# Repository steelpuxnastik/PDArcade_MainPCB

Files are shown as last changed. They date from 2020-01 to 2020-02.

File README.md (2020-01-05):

# PCB mainboard (with changes) for a homemade arcade controller for Hatsune Miku Project DIVA Arcade Future Tone. Based on http://pol.dip.jp/diva/

First version (homemade)
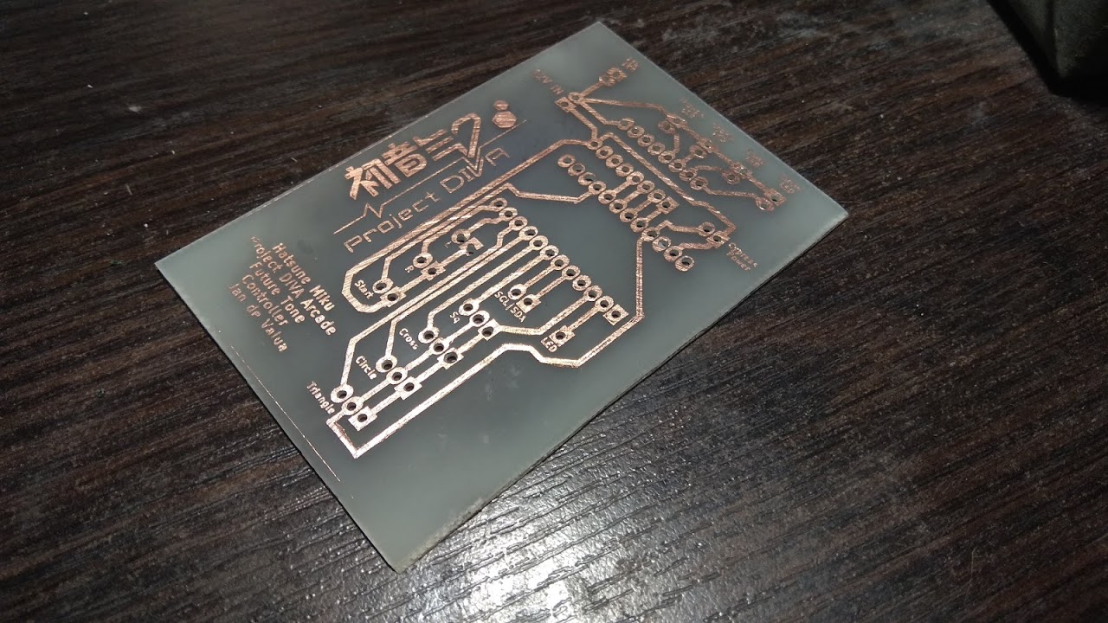
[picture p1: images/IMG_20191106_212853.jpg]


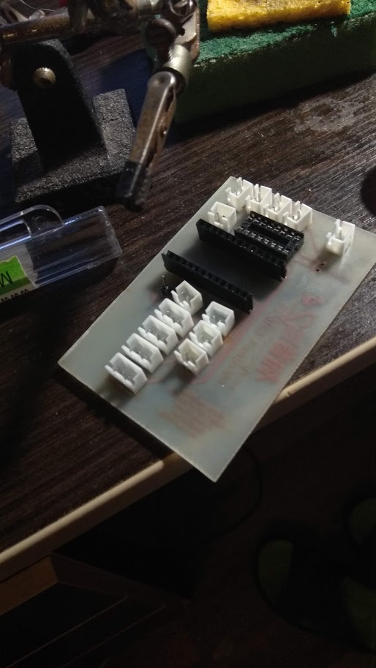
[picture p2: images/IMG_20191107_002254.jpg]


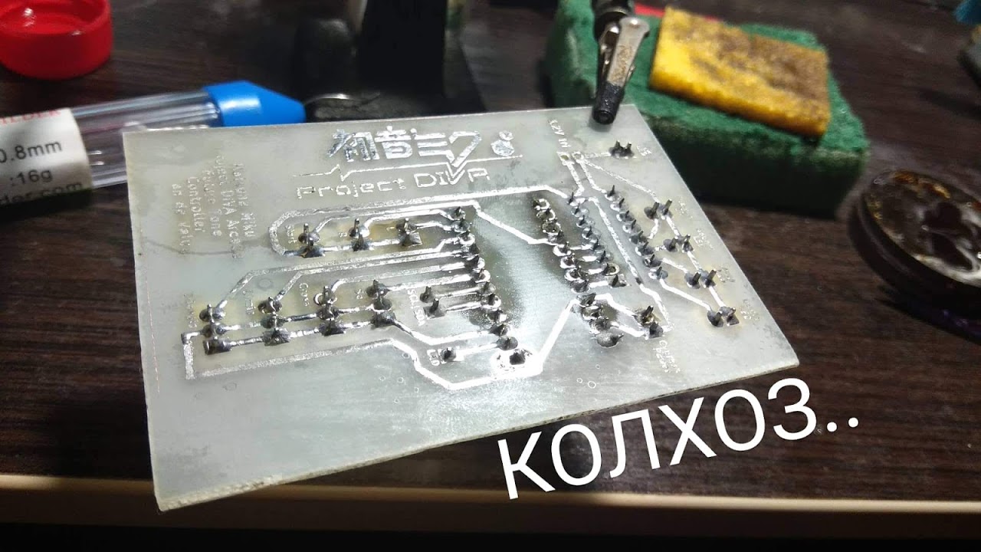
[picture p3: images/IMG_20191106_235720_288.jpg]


First version (factory made)
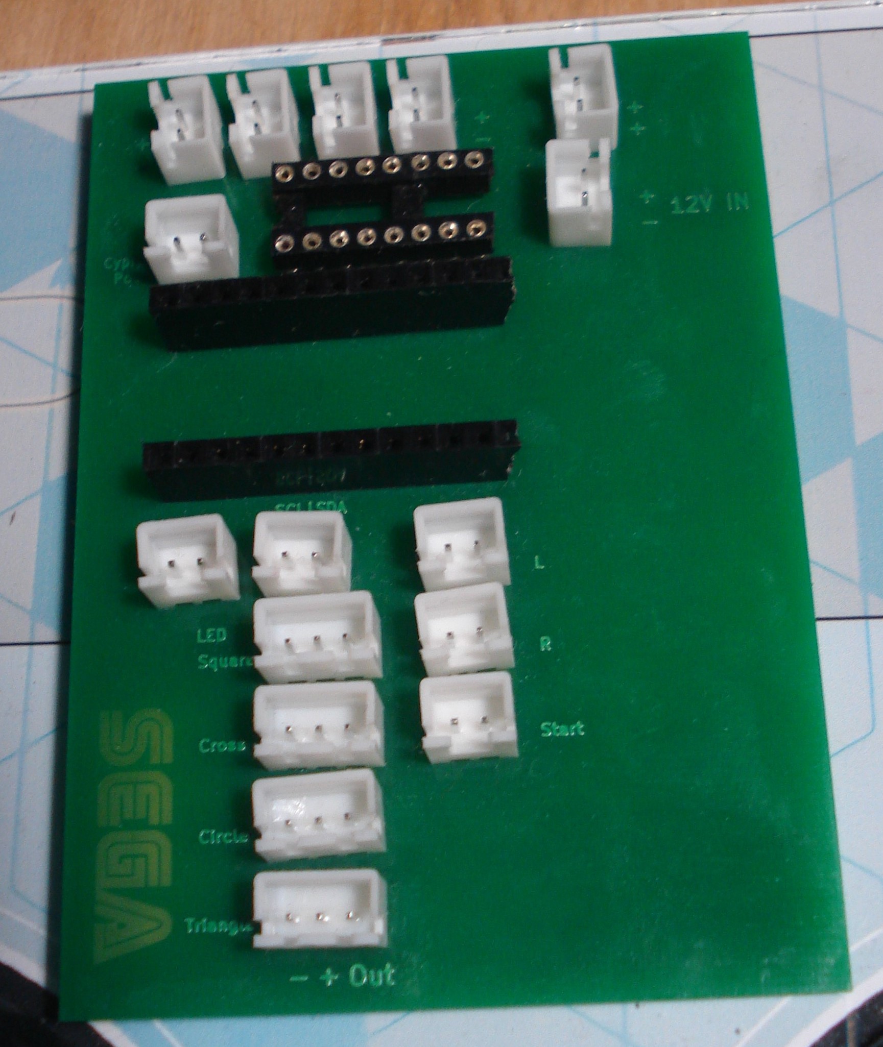
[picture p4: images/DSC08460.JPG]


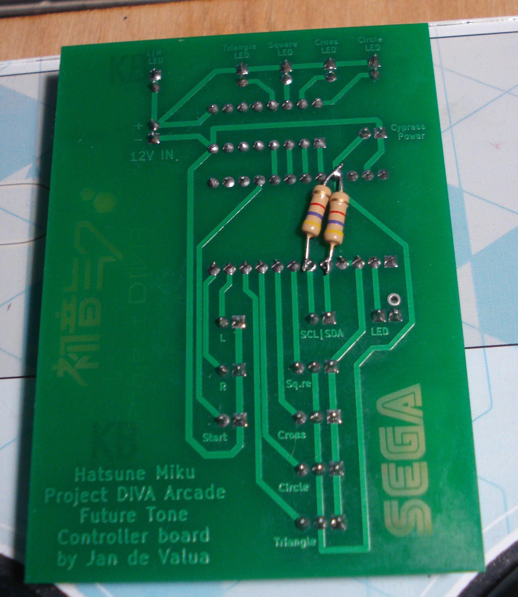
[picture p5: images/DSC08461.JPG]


In last commits it has some changes, most noticeable are holes for a 4,7k resistors for I2C connestion with CY8CKIT-049-4200 (I do not know why I didn't add it on the beginning) and visual changes (using a SilkS layers and ground mask). Also I added mounting holes for a DC/DC stepdown converter, it will be useful if you'll use 5V WS2812b LED strip, because LEDs in button use 12V, but strip 5V.

© ® ™All trademarks are the property of their respective owners. ™ ® ©

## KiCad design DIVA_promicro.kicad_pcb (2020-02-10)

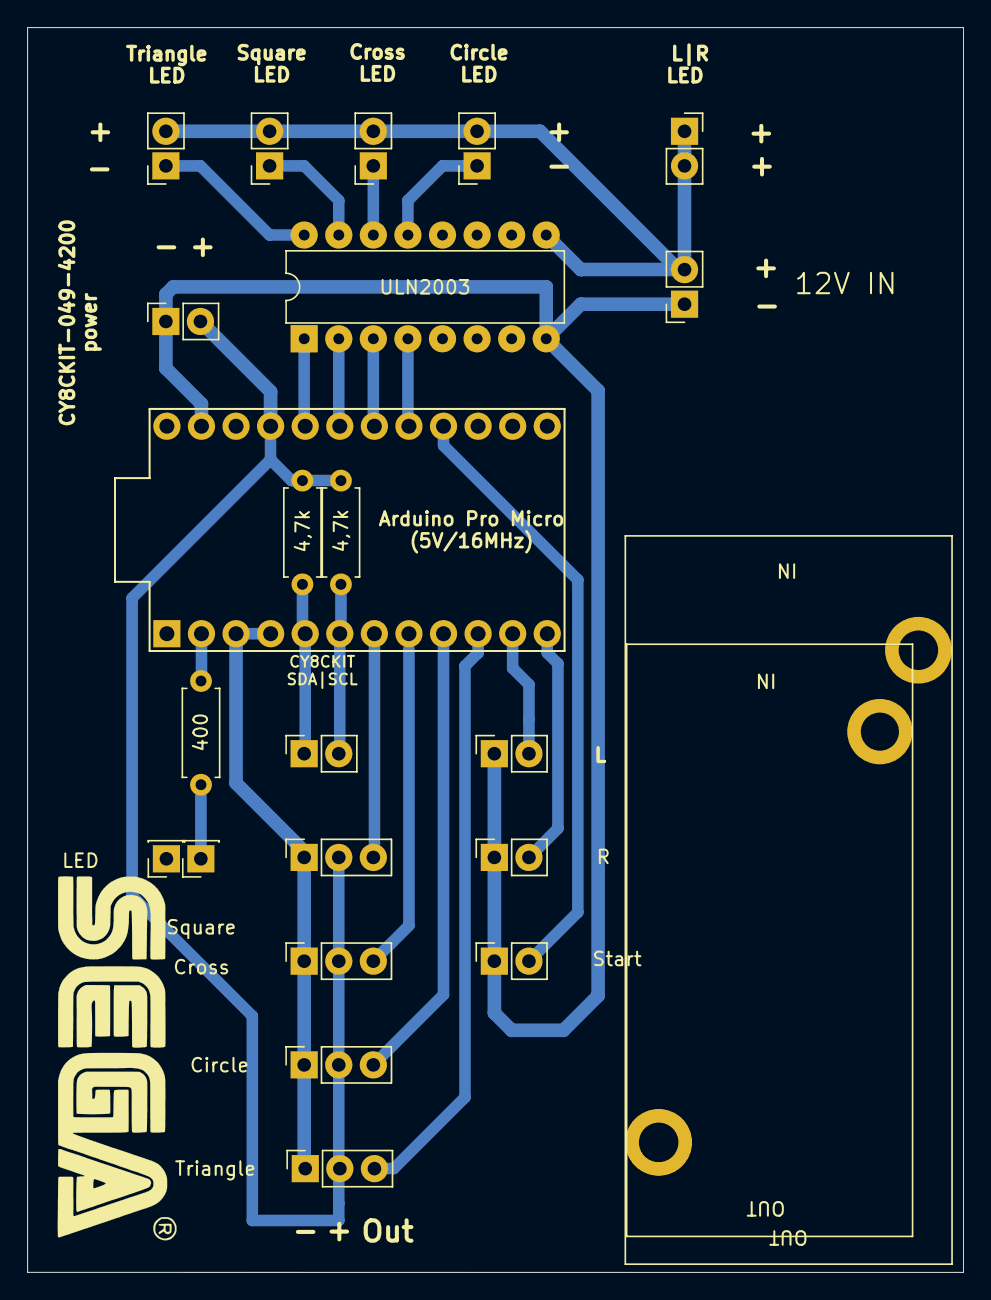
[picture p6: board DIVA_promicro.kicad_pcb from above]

Board: 2 copper layers, 68.8 x 91.4 mm, 22 parts (0 on the bottom side), 15 nets.

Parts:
4,7k, 4,7k#2: 4,7К; R_Axial_DIN0207_L6.3mm_D2.5mm_P7.62mm_Horizontal
12V IN: 12V_IN; PinSocket_1x02_P2.54mm_Vertical
400: 500; R_Axial_DIN0207_L6.3mm_D2.5mm_P7.62mm_Horizontal
CIRCLE_LED1: CIRCLE_LED_Conn_01x02; PinSocket_1x02_P2.54mm_Vertical
CROSS_LED1: CROSS_LED_Conn_01x02; PinSocket_1x02_P2.54mm_Vertical
CY8CKIT SDA|SCL: I2C_Conn_01x02; PinSocket_1x02_P2.54mm_Vertical
Circle: CIRCLE_Conn_01x03; PinSocket_1x03_P2.54mm_Vertical
Cross: CROSS_Conn_01x03; PinSocket_1x03_P2.54mm_Vertical
CypressPower1: PowerToCypress_Conn_01x02; PinSocket_1x02_P2.54mm_Vertical
L: L_Button_Conn_01x02; PinSocket_1x02_P2.54mm_Vertical
L/R_LED1: LR_LED_Conn_01x02; PinSocket_1x02_P2.54mm_Vertical
LED, LED1: LED_Strip_Conn_01x01; PinSocket_1x01_P2.54mm_Vertical
ProMicro1: ProMicro
R: R_Button_Conn_01x02; PinSocket_1x02_P2.54mm_Vertical
SQUARE_LED1: SQUARE_LED_Conn_01x02; PinSocket_1x02_P2.54mm_Vertical
Square: SQUARE_Conn_01x03; PinSocket_1x03_P2.54mm_Vertical
Start: START_Conn_01x02; PinSocket_1x02_P2.54mm_Vertical
TRIANGLE_LED1: TRIANGLE_LED_Conn_01x02; PinSocket_1x02_P2.54mm_Vertical
Triangle: TRIANGLE_Conn_01x03; PinSocket_1x03_P2.54mm_Vertical
ULN2003: ULN2003; DIP-16_W7.62mm

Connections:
unnamed: 12V IN.1, Circle.1, Cross.1, CypressPower1.1, L.1, ProMicro1.3, ProMicro1.4, ProMicro1.23, R.1, Square.1, Start.1, Triangle.1, ULN2003.8
unnamed: 12V IN.2, CIRCLE_LED1.2, CROSS_LED1.2, L/R_LED1.1, L/R_LED1.2, SQUARE_LED1.2, TRIANGLE_LED1.2, ULN2003.9
unnamed: CIRCLE_LED1.1, ULN2003.13
unnamed: CROSS_LED1.1, ULN2003.14
unnamed: 4,7k.1, 4,7k#2.1, Circle.2, Cross.2, CypressPower1.2, ProMicro1.21, Square.2, Triangle.2
unnamed: 4,7k#2.2, CY8CKIT SDA|SCL.1, ProMicro1.5
unnamed: 4,7k.2, CY8CKIT SDA|SCL.2
unnamed: 400.2, LED1.1
unnamed: 400.1, ProMicro1.2
unnamed: ProMicro1.17, ULN2003.4
unnamed: ProMicro1.18, ULN2003.3
unnamed: ProMicro1.19, ULN2003.2
unnamed: ProMicro1.20, ULN2003.1
unnamed: SQUARE_LED1.1, ULN2003.15
unnamed: TRIANGLE_LED1.1, ULN2003.16

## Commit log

2019-11-27 Final board
    [DIVA_promicro.kicad_pcb, DIVA_promicro.sch]
2019-12-11 Added mounting holes for resistors
    Added mounting holes for two 4,7K resistors that used in I2C connection
    [DIVA_promicro-B_Cu.gbr, DIVA_promicro-B_Mask.gbr, DIVA_promicro-B_SilkS.gbr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]
2020-01-05 images + visual pcb changes
    [DIVA_promicro.kicad_pcb]
2020-01-05 Added mounting holes for a DC/DC step-down modules
    Added mounting holes for a DC/DC step-down modules XL4015 (bigger) and LM2596S (smaller) if you will install 5V WS2812B LED strip. But footprints for them need to be confirmed.
    [DIVA_promicro.kicad_pcb]
2020-02-10 Added resistor for a LED strip signal line
    [DIVA_promicro.kicad_pcb, DIVA_promicro.sch]
